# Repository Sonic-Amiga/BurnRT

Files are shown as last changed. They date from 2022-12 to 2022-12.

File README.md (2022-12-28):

# BurnRT fuse ROM programmer

 This is a programmer for old OTP fuse PROM chips. Developed and tested with russian
556РТ (556RT) series, however should also be able to work with Western analogs.

 The project has been restored from old P-CAD sources, shared on the original project
forum (https://zx-pk.ru/threads/15617-programmator-ppzu-155re3-556rt4-i-drugikh ;
russian language).

Current versions:

* Hardware v2.3
* Software v2.0
* Firmware v1.1
* Case v1.0

Unfortunately at the moment only a binary version of the software for Windows OS is available.

# Supported chips

155РЕ3 (155RE3), western analogs SN74188N, N8223N
556РТ4 (556RT4), western analog 82S126
556РТ11 (556RT11), western analog 82S129
556РТ5 (556RT5), western analog IP3604
556РТ17 (556RT17), western analog IP3624A
556РТ6 (556RT6)
556РТ7 (556RT7)
556РТ12, western analog N82S136
556РТ13, western analog N82S137
556РТ14 (556RT14)
556РТ15 (556RT15)

# Distribution

There was originally no clear license terms defined. I asked at least one of original authors
of the schematic; he was not against me opensourcing the design. I am not a fan of this legal
stuff; let's consider it public domain. Any improvements are welcome; i will gladly accept them
into the repository.

3D printed case design is licensed under Creative Commons license: https://www.thingiverse.com/thing:2911557

# Contacts

Please direct all questions to pavel_fedin@mail.ru or to the aforementioned forum.

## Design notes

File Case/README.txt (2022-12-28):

BurnRT programmer case by EvRU on Thingiverse: https://www.thingiverse.com/thing:2911557

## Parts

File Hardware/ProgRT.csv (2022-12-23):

Source: | D:\Projects\BurnRT\ProgRT_USB_KiCAD\ProgRT.kicad_sch
Date: | 11/21/2022 12:37:46 AM
Tool: | Eeschema (6.0.9)
Generator: | C:\Program Files\KiCad\6.0\bin\scripting\plugins/bom_csv_grouped_by_value.py
Component Count: | 68
Individual Components:
Item | Qty | Reference(s) | Value | LibPart | Footprint | Datasheet | Value
 |  | C1 | 22p | ProgRT-eagle-import:K10-17_1 | Capacitor_SMD:C_0805_2012Metric_Pad1.18x1.45mm_HandSolder |  | K10-17_1
 |  | C2 | 22p | ProgRT-eagle-import:K10-17_1 | Capacitor_SMD:C_0805_2012Metric_Pad1.18x1.45mm_HandSolder |  | K10-17_1
 |  | C3 | 220n | ProgRT-eagle-import:K10-17_1 | Capacitor_SMD:C_0805_2012Metric_Pad1.18x1.45mm_HandSolder |  | 220n
 |  | C4 | 100n | ProgRT-eagle-import:K10-17_1 | Capacitor_SMD:C_0805_2012Metric_Pad1.18x1.45mm_HandSolder |  | 100n
 |  | C5 | 100u 35V | ProgRT-eagle-import:K50-35_470UF__1 | Capacitor_THT:CP_Radial_D5.0mm_P2.50mm |  | 100u 35V
 |  | C6 | 100u 25V | ProgRT-eagle-import:K50-35_1 | Capacitor_THT:CP_Radial_D5.0mm_P2.50mm |  | 100u 25V
 |  | C7 | 100n | ProgRT-eagle-import:K10-17_1 | Capacitor_SMD:C_0805_2012Metric_Pad1.18x1.45mm_HandSolder |  | 100n
 |  | C8 | 100n | ProgRT-eagle-import:K10-17_1 | Capacitor_SMD:C_0805_2012Metric_Pad1.18x1.45mm_HandSolder |  | 100n
 |  | DA1 | DG408 | ProgRT-eagle-import:590KN6_1 | Package_SO:SOIC-16_3.9x9.9mm_P1.27mm |  | DG408
 |  | DA2 | 78M12 | ProgRT-eagle-import:7812_1 | Package_TO_SOT_SMD:TO-252-2 |  | 7812_1
 |  | DA3 | 78M05 | ProgRT-eagle-import:7805_1 | Package_TO_SOT_SMD:TO-252-2 |  | 7805_1
 |  | DD1 | PIC18F2550 | ProgRT-eagle-import:PIC18F2550_1 | Package_SO:SOIC-28W_7.5x18.7mm_P1.27mm |  | PIC18F2550
 |  | DD2 | 74HC574D | :1533IR37_1_2 | Package_SO:SOIC-20W_7.5x12.8mm_P1.27mm |  | 74HC574D
 |  | DD3 | 74HC574D | :1533IR37_1_2 | Package_SO:SOIC-20W_7.5x12.8mm_P1.27mm |  | 74HC574D
 |  | R1 | 4.7K | ProgRT-eagle-import:MLT_0125_B_1 | Resistor_SMD:R_0805_2012Metric_Pad1.20x1.40mm_HandSolder |  | MLT_0125_B_1
 |  | R2 | 5.1K | ProgRT-eagle-import:MLT_0125_B_1 | Resistor_SMD:R_0805_2012Metric_Pad1.20x1.40mm_HandSolder |  | 5.1K
 |  | R3 | 10K | ProgRT-eagle-import:MLT_0125_B_1 | Resistor_SMD:R_0805_2012Metric_Pad1.20x1.40mm_HandSolder |  | MLT_0125_B_1
 |  | R4 | 10K | ProgRT-eagle-import:MLT_0125_B_1 | Resistor_SMD:R_0805_2012Metric_Pad1.20x1.40mm_HandSolder |  | 10K
 |  | R5 | 10K | ProgRT-eagle-import:MLT_0125_B_1 | Resistor_SMD:R_0805_2012Metric_Pad1.20x1.40mm_HandSolder |  | 10K
 |  | R6 | 10K | ProgRT-eagle-import:MLT_0125_B_1 | Resistor_SMD:R_0805_2012Metric_Pad1.20x1.40mm_HandSolder |  | 10K
 |  | R7 | 47 | ProgRT-eagle-import:MLT_05_B_1 | Resistor_SMD:R_2512_6332Metric_Pad1.40x3.35mm_HandSolder |  | MLT_05_B_1
 |  | R8 | 5.1K | ProgRT-eagle-import:MLT_0125_B_1 | Resistor_SMD:R_0805_2012Metric_Pad1.20x1.40mm_HandSolder |  | MLT_0125_B_1
 |  | R9 | 430 | ProgRT-eagle-import:MLT_0125_B_1 | Resistor_SMD:R_0805_2012Metric_Pad1.20x1.40mm_HandSolder |  | 430
 |  | R10 | 10K | ProgRT-eagle-import:MLT_0125_B_1 | Resistor_SMD:R_0805_2012Metric_Pad1.20x1.40mm_HandSolder |  | MLT_0125_B_1
 |  | R11 | 5.1K | ProgRT-eagle-import:MLT_0125_B_1 | Resistor_SMD:R_0805_2012Metric_Pad1.20x1.40mm_HandSolder |  | MLT_0125_B_1
 |  | R12 | 430 | ProgRT-eagle-import:MLT_0125_B_1 | Resistor_SMD:R_0805_2012Metric_Pad1.20x1.40mm_HandSolder |  | MLT_0125_B_1
 |  | R13 | 5.1K | ProgRT-eagle-import:MLT_0125_B_1 | Resistor_SMD:R_0805_2012Metric_Pad1.20x1.40mm_HandSolder |  | MLT_0125_B_1
 |  | R14 | 10K | ProgRT-eagle-import:MLT_0125_B_1 | Resistor_SMD:R_0805_2012Metric_Pad1.20x1.40mm_HandSolder |  | MLT_0125_B_1
 |  | R15 | 10K | ProgRT-eagle-import:MLT_0125_B_1 | Resistor_SMD:R_0805_2012Metric_Pad1.20x1.40mm_HandSolder |  | MLT_0125_B_1
 |  | VD1 | BZV55-C5V1 | ProgRT-eagle-import:KS133A_B_1 | Diode_SMD:D_SOD-123 |  | KS133A_B_1
 |  | VD2 | BZV55-C5V1 | ProgRT-eagle-import:KS133A_B_1 | Diode_SMD:D_SOD-123 |  | KS133A_B_1
 |  | VD3 | BZV55-C5V1 | ProgRT-eagle-import:KS133A_B_1 | Diode_SMD:D_SOD-123 |  | KS133A_B_1
 |  | VD4 | BZV55-C5V1 | ProgRT-eagle-import:KS133A_B_1 | Diode_SMD:D_SOD-123 |  | KS133A_B_1
 |  | VD5 | BZV55-C5V1 | ProgRT-eagle-import:KS133A_B_1 | Diode_SMD:D_SOD-123 |  | KS133A_B_1
 |  | VD6 | BZV55-C5V1 | ProgRT-eagle-import:KS133A_B_1 | Diode_SMD:D_SOD-123 |  | KS133A_B_1
 |  | VD7 | BZV55-C5V1 | ProgRT-eagle-import:KS133A_B_1 | Diode_SMD:D_SOD-123 |  | KS133A_B_1
 |  | VD8 | BZV55-C5V1 | ProgRT-eagle-import:KS133A_B_1 | Diode_SMD:D_SOD-123 |  | KS133A_B_1
 |  | VD9 | BZV55-C5V1 | ProgRT-eagle-import:KS133A_B_1 | Diode_SMD:D_SOD-123 |  | KS133A_B_1
 |  | VD10 | BZV55-C5V1 | ProgRT-eagle-import:KS133A_B_1 | Diode_SMD:D_SOD-123 |  | KS133A_B_1
 |  | VD11 | BZV55-C5V1 | ProgRT-eagle-import:KS133A_B_1 | Diode_SMD:D_SOD-123 |  | KS133A_B_1
 |  | VD12 | BZV55-C5V1 | ProgRT-eagle-import:KS133A_B_1 | Diode_SMD:D_SOD-123 |  | KS133A_B_1
 |  | VD13 | BZV55-C5V1 | ProgRT-eagle-import:KS133A_B_1 | Diode_SMD:D_SOD-123 |  | KS133A_B_1
 |  | VD14 | BZV55-C5V1 | ProgRT-eagle-import:KS133A_B_1 | Diode_SMD:D_SOD-123 |  | KS133A_B_1
 |  | VD15 | BZV55-C5V1 | ProgRT-eagle-import:KS133A_B_1 | Diode_SMD:D_SOD-123 |  | KS133A_B_1
 |  | VD16 | BZV55-C5V1 | ProgRT-eagle-import:KS133A_B_1 | Diode_SMD:D_SOD-123 |  | KS133A_B_1
 |  | VD17 | M7 | ProgRT-eagle-import:1N400X_B_1 | Diode_SMD:D_SMA |  | 1N400X_B_1
 |  | VD18 | LL4148 | ProgRT-eagle-import:KD522_B_1 | Diode_SMD:D_SMA |  | КД522
 |  | VD19 | M7 | ProgRT-eagle-import:1N400X_B_1 | Diode_SMD:D_SMA |  | 1N400X_B_1
 |  | VD20 | M7 | ProgRT-eagle-import:1N400X_B_1 | Diode_SMD:D_SMA |  | 1N400X
 |  | VD21 | LL4148 | ProgRT-eagle-import:KD522_B_1 | Diode_SMD:D_SMA |  | КД522
 |  | VD22 | M7 | ProgRT-eagle-import:1N400X_B_1 | Diode_SMD:D_SMA |  | 1N400X_B_1
 |  | VD23 | M7 | ProgRT-eagle-import:1N400X_B_1 | Diode_SMD:D_SMA |  | 1N400X
 |  | VD24 | GREEN | Socet.SCH.eagle-eagle-import:AL307_1 | Diode_SMD:D_SOD-123F |  | AL307_1
 |  | VD25 | RED | Socet.SCH.eagle-eagle-import:AL307_1 | Diode_SMD:D_SOD-123F |  | AL307_1
 |  | VT1 | MJD127G | :KT973_1_1 | Package_TO_SOT_SMD:TO-252-2 |  | KT973_1_1
 |  | VT2 | BCX56 | ProgRT-eagle-import:KT503_1 | Package_TO_SOT_SMD:SOT-89-3 |  | KT503_1
 |  | VT3 | BCX56 | ProgRT-eagle-import:KT503_1 | Package_TO_SOT_SMD:SOT-89-3 |  | KT503_1
 |  | VT4 | BCX56 | ProgRT-eagle-import:KT503_1 | Package_TO_SOT_SMD:SOT-89-3 |  | KT503_1
 |  | VT5 | MJD127G | :KT973_1_1 | Package_TO_SOT_SMD:TO-252-2 |  | KT973_1_1
 |  | VT6 | BCX56 | ProgRT-eagle-import:KT503_1 | Package_TO_SOT_SMD:SOT-89-3 |  | KT503_1
 |  | XP1 | DC-005_1 | ProgRT-eagle-import:DC-005_1 | Connector_BarrelJack:BarrelJack_GCT_DCJ200-10-A_Horizontal |  | DC-005_1
 |  | XP2 | USB_TYPE_B_1 | ProgRT-eagle-import:USB_TYPE_B_1 | Connector_USB:USB_Mini-B_Lumberg_2486_01_Horizontal |  | USB_TYPE_B_1
 |  | XP3 | Conn_01x06 | Connector_Generic:Conn_01x06 | Connector_PinHeader_2.54mm:PinHeader_1x06_P2.54mm_Vertical | ~ | Conn_01x06
 |  | XS3 | 155РЕ3 | Socet.SCH.eagle-eagle-import:155RE3_ZIF_1 | Socket:DIP_Socket-16_W4.3_W5.08_W7.62_W10.16_W10.9_3M_216-3340-00-0602J |  | 155РЕ3
 |  | XS4 | 556РT4 | Socet.SCH.eagle-eagle-import:556RT4_ZIF_1 | Socket:DIP_Socket-16_W4.3_W5.08_W7.62_W10.16_W10.9_3M_216-3340-00-0602J |  | 556РT4
 |  | XS5 | 556РТ14 | Socet.SCH.eagle-eagle-import:556RT14_ZIF_1 | Socket:DIP_Socket-18_W4.3_W5.08_W7.62_W10.16_W10.9_3M_218-3341-00-0602J |  | 556РТ14
 |  | XS6 | 556РТ16 | Socet.SCH.eagle-eagle-import:556RT16_ZIF_1 | Socket:DIP_Socket-24_W11.9_W12.7_W15.24_W17.78_W18.5_3M_224-1275-00-0602J |  | 556РТ16
 |  | ZQ1 | 20 MHz | Device:Crystal | Crystal:Crystal_HC49-U_Vertical | ~ | Crystal
Collated Components:
Item | Qty | Reference(s) | Value | LibPart | Footprint | Datasheet | Value
1 | 2 | C1, C2 | 22p | ProgRT-eagle-import:K10-17_1 | Capacitor_SMD:C_0805_2012Metric_Pad1.18x1.45mm_HandSolder |  | K10-17_1
2 | 1 | C3 | 220n | ProgRT-eagle-import:K10-17_1 | Capacitor_SMD:C_0805_2012Metric_Pad1.18x1.45mm_HandSolder |  | 220n
3 | 3 | C4, C7, C8 | 100n | ProgRT-eagle-import:K10-17_1 | Capacitor_SMD:C_0805_2012Metric_Pad1.18x1.45mm_HandSolder |  | 100n
4 | 1 | C5 | 100u 35V | ProgRT-eagle-import:K50-35_470UF__1 | Capacitor_THT:CP_Radial_D5.0mm_P2.50mm |  | 100u 35V
5 | 1 | C6 | 100u 25V | ProgRT-eagle-import:K50-35_1 | Capacitor_THT:CP_Radial_D5.0mm_P2.50mm |  | 100u 25V
6 | 1 | DA1 | DG408 | ProgRT-eagle-import:590KN6_1 | Package_SO:SOIC-16_3.9x9.9mm_P1.27mm |  | DG408
7 | 1 | DA2 | 78M12 | ProgRT-eagle-import:7812_1 | Package_TO_SOT_SMD:TO-252-2 |  | 7812_1
8 | 1 | DA3 | 78M05 | ProgRT-eagle-import:7805_1 | Package_TO_SOT_SMD:TO-252-2 |  | 7805_1
9 | 1 | DD1 | PIC18F2550 | ProgRT-eagle-import:PIC18F2550_1 | Package_SO:SOIC-28W_7.5x18.7mm_P1.27mm |  | PIC18F2550
10 | 2 | DD2, DD3 | 74HC574D | :1533IR37_1_2 | Package_SO:SOIC-20W_7.5x12.8mm_P1.27mm |  | 74HC574D
11 | 1 | R1 | 4.7K | ProgRT-eagle-import:MLT_0125_B_1 | Resistor_SMD:R_0805_2012Metric_Pad1.20x1.40mm_HandSolder |  | MLT_0125_B_1
12 | 4 | R2, R8, R11, R13 | 5.1K | ProgRT-eagle-import:MLT_0125_B_1 | Resistor_SMD:R_0805_2012Metric_Pad1.20x1.40mm_HandSolder |  | 5.1K
13 | 7 | R3, R4, R5, R6, R10, R14, R15 | 10K | ProgRT-eagle-import:MLT_0125_B_1 | Resistor_SMD:R_0805_2012Metric_Pad1.20x1.40mm_HandSolder |  | 10K
14 | 1 | R7 | 47 | ProgRT-eagle-import:MLT_05_B_1 | Resistor_SMD:R_2512_6332Metric_Pad1.40x3.35mm_HandSolder |  | MLT_05_B_1
15 | 2 | R9, R12 | 430 | ProgRT-eagle-import:MLT_0125_B_1 | Resistor_SMD:R_0805_2012Metric_Pad1.20x1.40mm_HandSolder |  | 430
16 | 16 | VD1, VD2, VD3, VD4, VD5, VD6, VD7, VD8, VD9, VD10, VD11, VD12, VD13, VD14, VD15, VD16 | BZV55-C5V1 | ProgRT-eagle-import:KS133A_B_1 | Diode_SMD:D_SOD-123 |  | KS133A_B_1
17 | 5 | VD17, VD19, VD20, VD22, VD23 | M7 | ProgRT-eagle-import:1N400X_B_1 | Diode_SMD:D_SMA |  | 1N400X
18 | 2 | VD18, VD21 | LL4148 | ProgRT-eagle-import:KD522_B_1 | Diode_SMD:D_SMA |  | КД522
19 | 1 | VD24 | GREEN | Socet.SCH.eagle-eagle-import:AL307_1 | Diode_SMD:D_SOD-123F |  | AL307_1
20 | 1 | VD25 | RED | Socet.SCH.eagle-eagle-import:AL307_1 | Diode_SMD:D_SOD-123F |  | AL307_1
21 | 2 | VT1, VT5 | MJD127G | :KT973_1_1 | Package_TO_SOT_SMD:TO-252-2 |  | KT973_1_1
22 | 4 | VT2, VT3, VT4, VT6 | BCX56 | ProgRT-eagle-import:KT503_1 | Package_TO_SOT_SMD:SOT-89-3 |  | KT503_1
23 | 1 | XP1 | DC-005_1 | ProgRT-eagle-import:DC-005_1 | Connector_BarrelJack:BarrelJack_GCT_DCJ200-10-A_Horizontal |  | DC-005_1
24 | 1 | XP2 | USB_TYPE_B_1 | ProgRT-eagle-import:USB_TYPE_B_1 | Connector_USB:USB_Mini-B_Lumberg_2486_01_Horizontal |  | USB_TYPE_B_1
25 | 1 | XP3 | Conn_01x06 | Connector_Generic:Conn_01x06 | Connector_PinHeader_2.54mm:PinHeader_1x06_P2.54mm_Vertical | ~ | Conn_01x06
26 | 1 | XS3 | 155РЕ3 | Socet.SCH.eagle-eagle-import:155RE3_ZIF_1 | Socket:DIP_Socket-16_W4.3_W5.08_W7.62_W10.16_W10.9_3M_216-3340-00-0602J |  | 155РЕ3
27 | 1 | XS4 | 556РT4 | Socet.SCH.eagle-eagle-import:556RT4_ZIF_1 | Socket:DIP_Socket-16_W4.3_W5.08_W7.62_W10.16_W10.9_3M_216-3340-00-0602J |  | 556РT4
28 | 1 | XS5 | 556РТ14 | Socet.SCH.eagle-eagle-import:556RT14_ZIF_1 | Socket:DIP_Socket-18_W4.3_W5.08_W7.62_W10.16_W10.9_3M_218-3341-00-0602J |  | 556РТ14
29 | 1 | XS6 | 556РТ16 | Socet.SCH.eagle-eagle-import:556RT16_ZIF_1 | Socket:DIP_Socket-24_W11.9_W12.7_W15.24_W17.78_W18.5_3M_224-1275-00-0602J |  | 556РТ16
30 | 1 | ZQ1 | 20 MHz | Device:Crystal | Crystal:Crystal_HC49-U_Vertical | ~ | Crystal

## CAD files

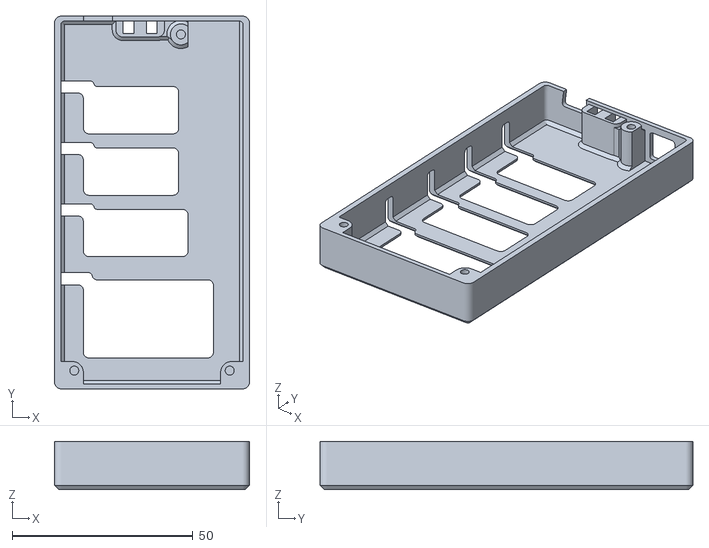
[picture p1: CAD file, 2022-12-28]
Case/burnrt_case_top.stl
54.0 x 103.2 x 13.4

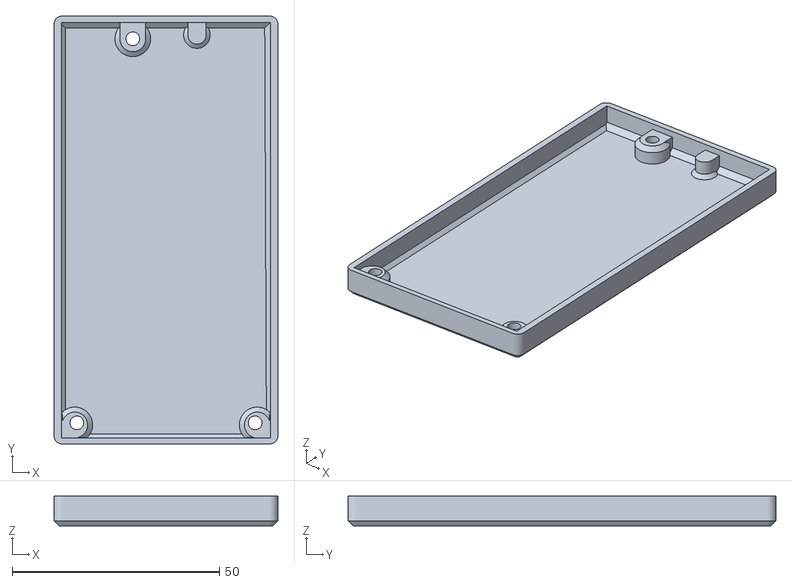
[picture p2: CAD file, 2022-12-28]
Case/burnrt_case_bottom.stl
54.0 x 103.2 x 7.20

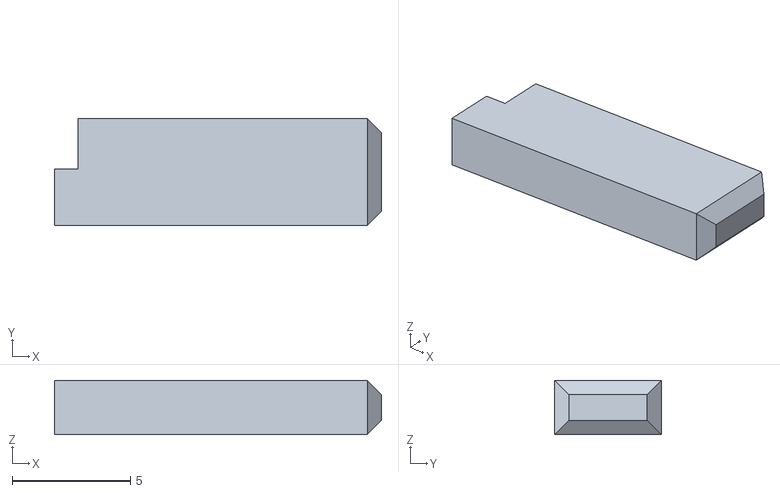
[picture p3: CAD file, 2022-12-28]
Case/burnrt_case_light.stl
13.8 x 4.51 x 2.28

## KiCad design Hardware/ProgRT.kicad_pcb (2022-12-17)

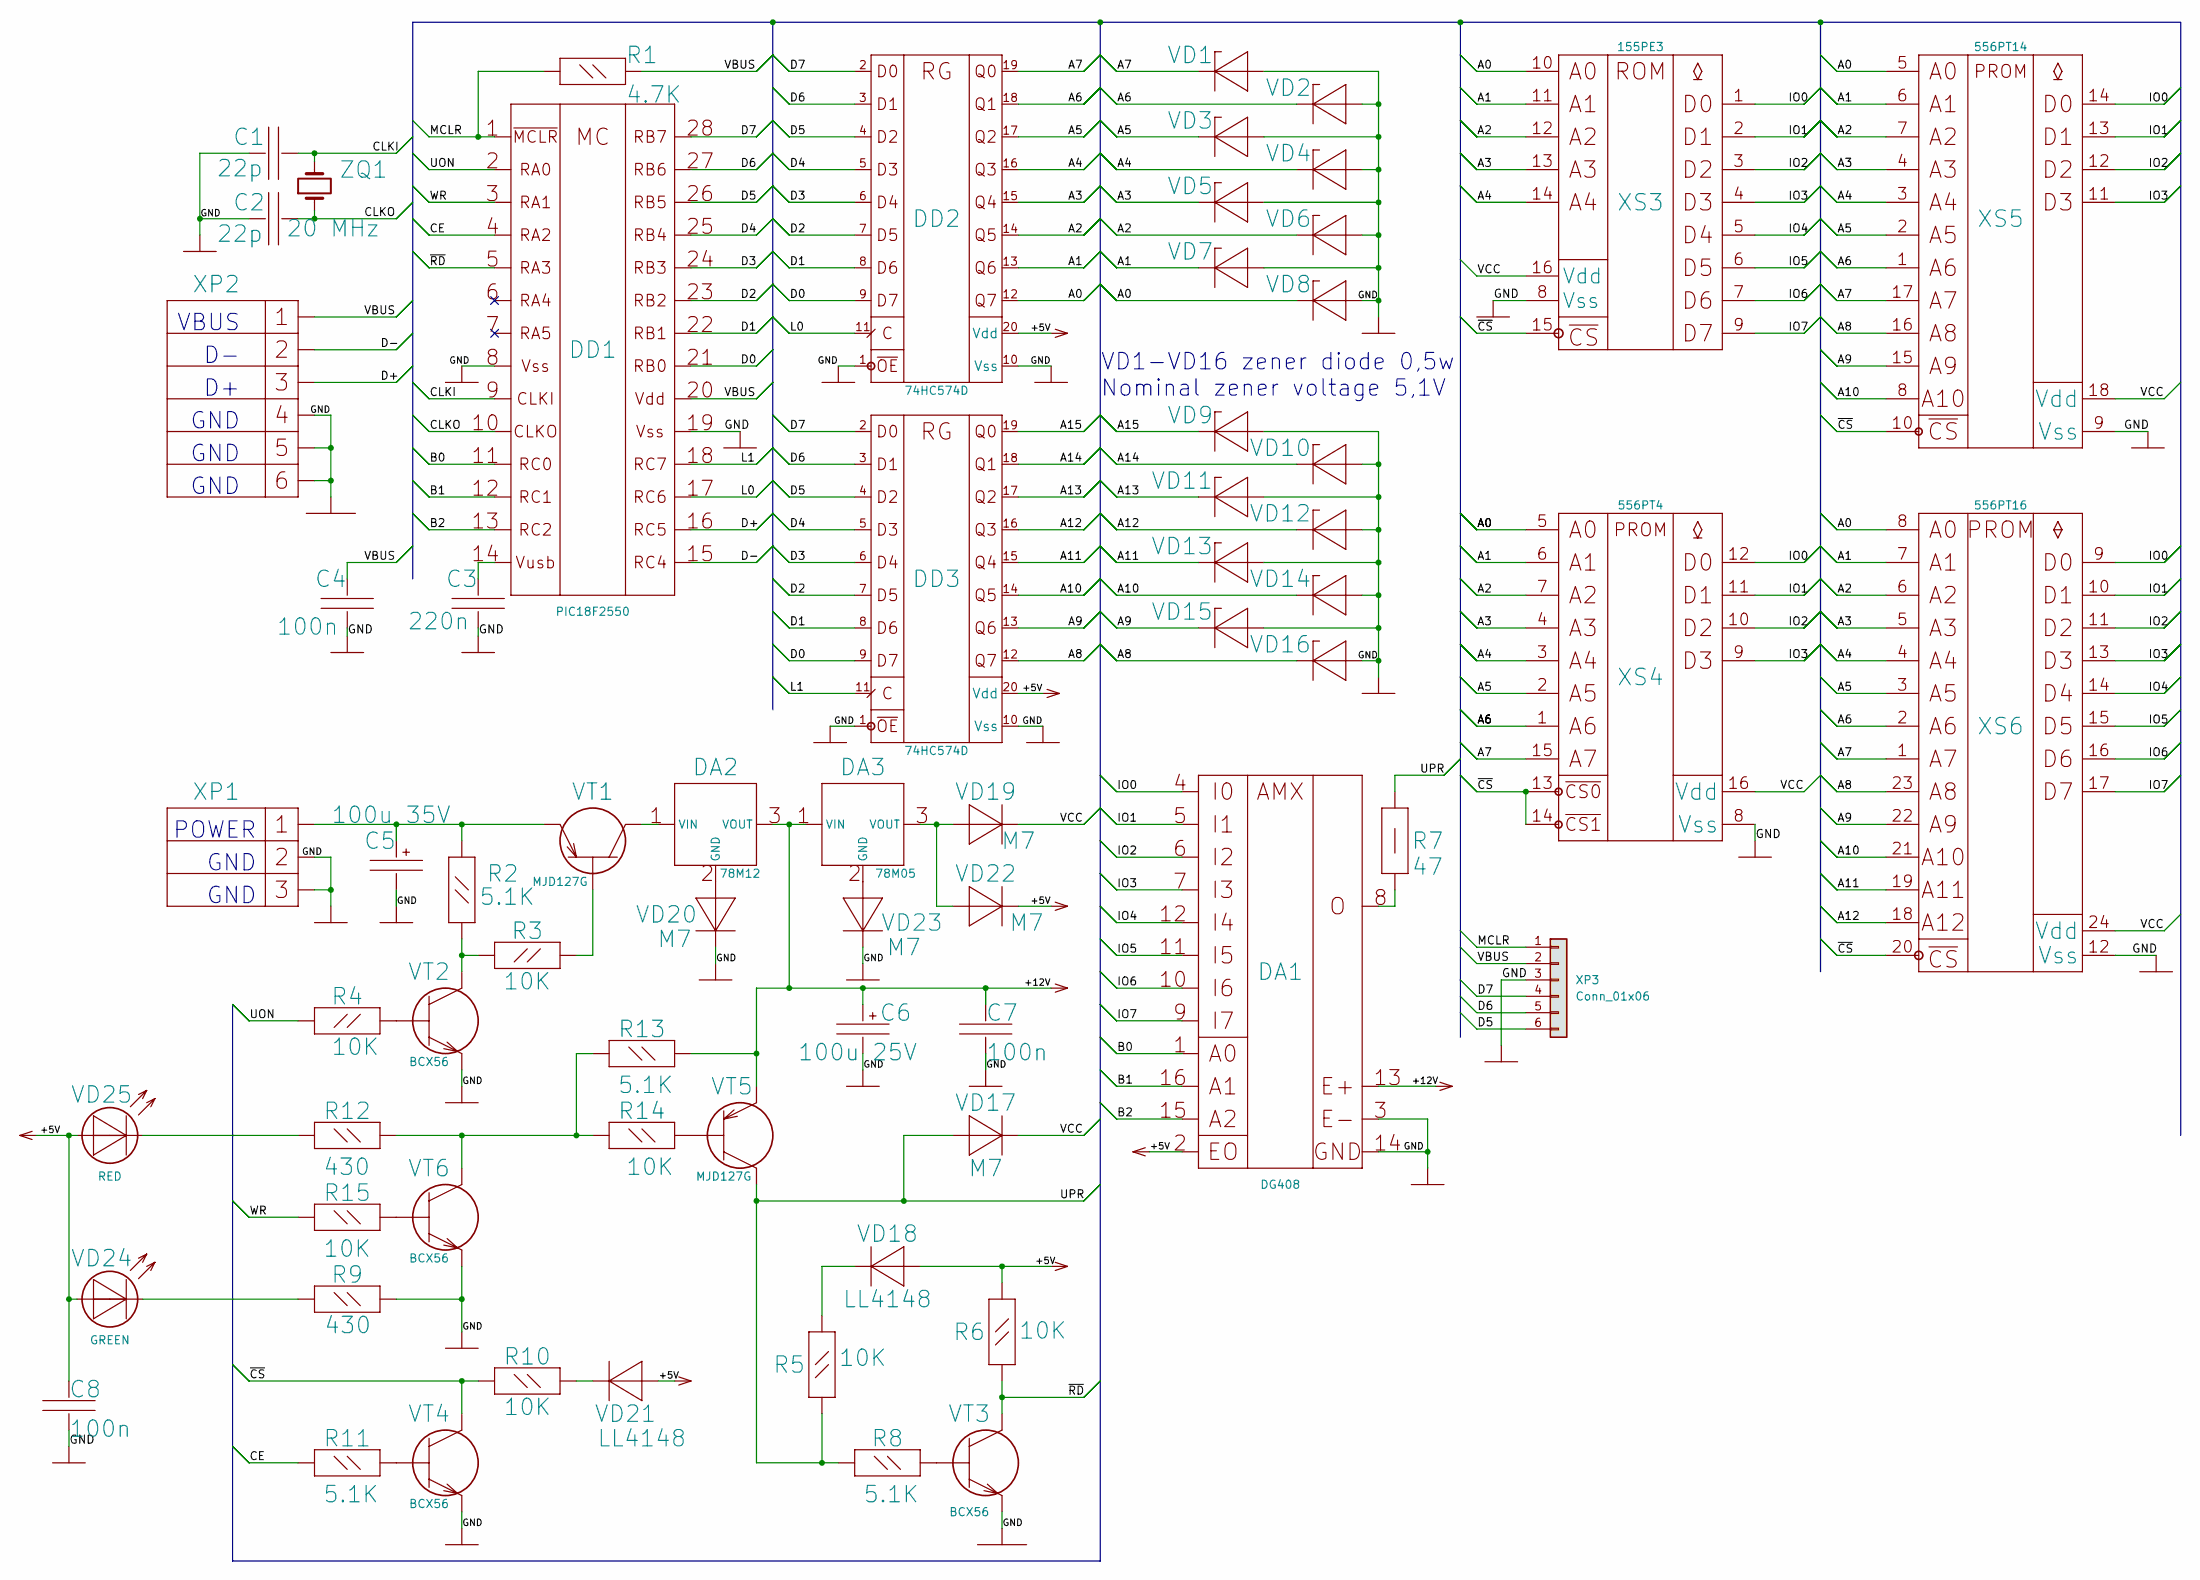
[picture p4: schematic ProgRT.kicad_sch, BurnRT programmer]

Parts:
C1, C2: 22p; C_0805_2012Metric_Pad1.18x1.45mm_HandSolder
C3: 220n; C_0805_2012Metric_Pad1.18x1.45mm_HandSolder
C4, C7: 100n; C_0805_2012Metric_Pad1.18x1.45mm_HandSolder
C5: 100u 35V; CP_Radial_D8.0mm_P3.80mm
C6: 100u 25V; CP_Radial_D8.0mm_P3.80mm
C8: 100n; C_1206_3216Metric_Pad1.33x1.80mm_HandSolder
DA1: DG408; SOIC-16_3.9x9.9mm_P1.27mm
DA2: 78M12; TO-252-2
DA3: 78M05; TO-252-2
DD1: PIC18F2550; SOIC-28W_7.5x18.7mm_P1.27mm
DD2, DD3: 74HC574D; SOIC-20W_7.5x12.8mm_P1.27mm
R1: 4.7K; R_0805_2012Metric_Pad1.20x1.40mm_HandSolder
R2, R8, R11, R13: 5.1K; R_0805_2012Metric_Pad1.20x1.40mm_HandSolder
R3: R_0805_2012Metric_Pad1.20x1.40mm_HandSolder
R4, R5, R6, R10, R14, R15: 10K; R_0805_2012Metric_Pad1.20x1.40mm_HandSolder
R7: 47; R_2512_6332Metric_Pad1.40x3.35mm_HandSolder
R9, R12: 430; R_0805_2012Metric_Pad1.20x1.40mm_HandSolder
VD1, VD2, VD3, VD4, VD5, VD6, VD7, VD8, VD9, VD10, VD11, VD12, VD13, VD14, VD15, VD16: BZV55-C5V1; D_MiniMELF
VD17, VD19, VD20, VD22: M7; D_SMA
VD18, VD21: LL4148; D_SMA
VD23: D_SMA
VD24: GREEN; LED_1206_3216Metric_Pad1.42x1.75mm_HandSolder
VD25: RED; LED_1206_3216Metric_Pad1.42x1.75mm_HandSolder
VT1, VT5: MJD127G; TO-252-2
VT2, VT3, VT4, VT6: BCX56; SOT-89-3
XP1: DC-005_1; BarrelJack_GCT_DCJ200-10-A_Horizontal
XP2: USB_TYPE_B_1; USB_Mini-B_Lumberg_2486_01_Horizontal
XP3: Conn_01x06; PinHeader_1x06_P2.54mm_Vertical
XS3: 155РЕ3; DIP_Socket-16_W4.3_W5.08_W7.62_W10.16_W10.9_3M_216-3340-00-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
XS4: 556РT4; DIP_Socket-16_W4.3_W5.08_W7.62_W10.16_W10.9_3M_216-3340-00-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
XS5: 556РТ14; DIP_Socket-18_W4.3_W5.08_W7.62_W10.16_W10.9_3M_218-3341-00-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
XS6: 556РТ16; DIP_Socket-24_W11.9_W12.7_W15.24_W17.78_W18.5_3M_224-1275-0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
ZQ1: 20 MHz; Crystal_HC49-U_Vertical

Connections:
/A0: DD2.12 (Q7), VD8.1 (C), XS3.10 (A0), XS4.5 (A0), XS5.5 (A0), XS6.8 (A0)
/A1: DD2.13 (Q6), VD7.1 (C), XS3.11 (A1), XS4.6 (A1), XS5.6 (A1), XS6.7 (A1)
/A2: DD2.14 (Q5), VD6.1 (C), XS3.12 (A2), XS4.7 (A2), XS5.7 (A2), XS6.6 (A2)
/A3: DD2.15 (Q4), VD5.1 (C), XS3.13 (A3), XS4.4 (A3), XS5.4 (A3), XS6.5 (A3)
/A4: DD2.16 (Q3), VD4.1 (C), XS3.14 (A4), XS4.3 (A4), XS5.3 (A4), XS6.4 (A4)
/A5: DD2.17 (Q2), VD3.1 (C), XS4.2 (A5), XS5.2 (A5), XS6.3 (A5)
/A6: DD2.18 (Q1), VD2.1 (C), XS4.1 (A6), XS5.1 (A6), XS6.2 (A6)
/A7: DD2.19 (Q0), VD1.1 (C), XS4.15 (A7), XS5.17 (A7), XS6.1 (A7)
/A8: DD3.12 (Q7), VD16.1 (C), XS5.16 (A8), XS6.23 (A8)
/A9: DD3.13 (Q6), VD15.1 (C), XS5.15 (A9), XS6.22 (A9)
/A10: DD3.14 (Q5), VD14.1 (C), XS5.8 (A10), XS6.21 (A10)
/A11: DD3.15 (Q4), VD13.1 (C), XS6.19 (A11)
/A12: DD3.16 (Q3), VD12.1 (C), XS6.18 (A12)
/A13: DD3.17 (Q2), VD11.1 (C)
/A14: DD3.18 (Q1), VD10.1 (C)
/A15: DD3.19 (Q0), VD9.1 (C)
/B0: DA1.1 (A0), DD1.11 (RC0)
/B1: DA1.16 (A1), DD1.12 (RC1)
/B2: DA1.15 (A2), DD1.13 (RC2)
/CE: DD1.4 (RA2), R11.1
/CLKI: C1.1 (2), DD1.9 (CLKI), ZQ1.2
/CLKO: C2.1 (2), DD1.10 (CLKO), ZQ1.1
/D0: DD1.21 (RB0), DD2.9 (D7), DD3.9 (D7)
/D1: DD1.22 (RB1), DD2.8 (D6), DD3.8 (D6)
/D2: DD1.23 (RB2), DD2.7 (D5), DD3.7 (D5)
/D3: DD1.24 (RB3), DD2.6 (D4), DD3.6 (D4)
/D4: DD1.25 (RB4), DD2.5 (D3), DD3.5 (D3)
/D5: DD1.26 (RB5), DD2.4 (D2), DD3.4 (D2), XP3.6
/D6: DD1.27 (RB6), DD2.3 (D1), DD3.3 (D1), XP3.5
/D7: DD1.28 (RB7), DD2.2 (D0), DD3.2 (D0), XP3.4
/D+: DD1.16 (RC5), XP2.3 (D+)
/D-: DD1.15 (RC4), XP2.2 (D-)
/GND: C1.2 (1), C2.2 (1), C3.2 (1), C4.2 (1), C5.2, C6.2, C7.1 (2), C8.1 (2), DA1.3 (E-), DA1.14 (GND), DD1.8 (VSS@1), DD1.19 (VSS@2), DD2.1 (!OE), DD2.10 (Vss), DD3.1 (!OE), DD3.10 (Vss), R9.1, VD1.2 (A), VD2.2 (A), VD3.2 (A), VD4.2 (A), VD5.2 (A), VD6.2 (A), VD7.2 (A), VD8.2 (A), VD9.2 (A), VD10.2 (A), VD11.2 (A), VD12.2 (A), VD13.2 (A), VD14.2 (A), VD15.2 (A), VD16.2 (A), VD20.1 (C), VD23.1 (C), VT2.3 (E), VT3.3 (E), VT4.3 (E), VT6.3 (E), XP1.2, XP1.3, XP2.4 (GND@2), XP2.5 (GND@1), XP2.6 (GND@3), XP3.3, XS3.8 (Vss), XS4.8 (Vss), XS5.9 (Vss), XS6.12 (Vss)
/IO0: DA1.4 (I0), XS3.1 (D0), XS4.12 (D0), XS5.14 (D0), XS6.9 (D0)
/IO1: DA1.5 (I1), XS3.2 (D1), XS4.11 (D1), XS5.13 (D1), XS6.10 (D1)
/IO2: DA1.6 (I2), XS3.3 (D2), XS4.10 (D2), XS5.12 (D2), XS6.11 (D2)
/IO3: DA1.7 (I3), XS3.4 (D3), XS4.9 (D3), XS5.11 (D3), XS6.13 (D3)
/IO4: DA1.12 (I4), XS3.5 (D4), XS6.14 (D4)
/IO5: DA1.11 (I5), XS3.6 (D5), XS6.15 (D5)
/IO6: DA1.10 (I6), XS3.7 (D6), XS6.16 (D6)
/IO7: DA1.9 (I7), XS3.9 (D7), XS6.17 (D7)
/L0: DD1.17 (RC6), DD2.11 (C)
/L1: DD1.18 (RC7), DD3.11 (C)
/MCLR: DD1.1 (!MCLR), R1.1, XP3.1
/UON: DD1.2 (RA0), R4.1
/UPR: R5.1, R7.1, R8.1, VD17.2 (A), VT5.2 (C)
/VBUS: C4.1 (2), DD1.20 (VDD), R1.2, XP2.1 (VBUS), XP3.2
/VCC: VD17.1 (C), VD19.1 (C), XS3.16 (Vdd), XS4.16 (Vdd), XS5.18 (Vdd), XS6.24 (Vdd)
/WR: DD1.3 (RA1), R15.1
/~CS: R10.1, VT4.2 (C), XS3.15 (!CS), XS4.13 (~CS0), XS4.14 (~CS1), XS5.10 (!CS), XS6.20 (~CS)
/~RD: DD1.5 (RA3), R6.1, VT3.2 (C)
unnamed: C3.1 (2), DD1.14 (VUSB)
unnamed: C5.1, R2.2, VT1.3 (E), XP1.1
unnamed: DA1.8 (O), R7.2
unnamed: DA2.1 (VIN), VT1.2 (C)
unnamed: DA2.2 (GND), VD20.2 (A)
unnamed: DA3.2 (GND), VD23.2 (A)
unnamed: DA3.3 (VOUT), VD19.2 (A), VD22.2 (A)
unnamed: R2.1, R3.1, VT2.2 (C)
unnamed: R3.2, VT1.1 (B)
unnamed: R4.2, VT2.1 (B)
unnamed: R5.2, VD18.1 (C)
unnamed: R8.2, VT3.1 (B)
unnamed: R9.2, VD24.1 (C)
unnamed: R10.2, VD21.1 (C)
unnamed: R11.2, VT4.1 (B)
unnamed: R12.1, VD25.1 (C)
unnamed: R12.2, R13.1, R14.1, VT6.2 (C)
unnamed: R14.2, VT5.1 (B)
unnamed: R15.2, VT6.1 (B)

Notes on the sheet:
GND
VBUS
POWER
VD1-VD16 zener diode 0,5w Nominal zener voltage 5,1V

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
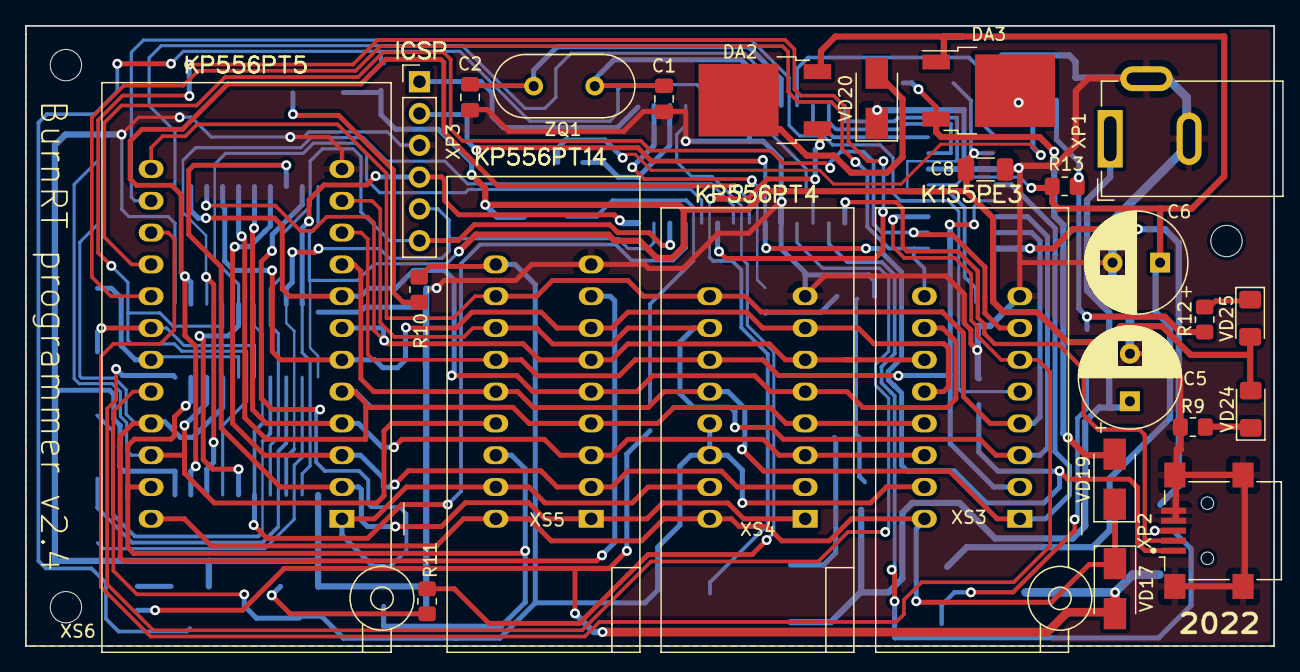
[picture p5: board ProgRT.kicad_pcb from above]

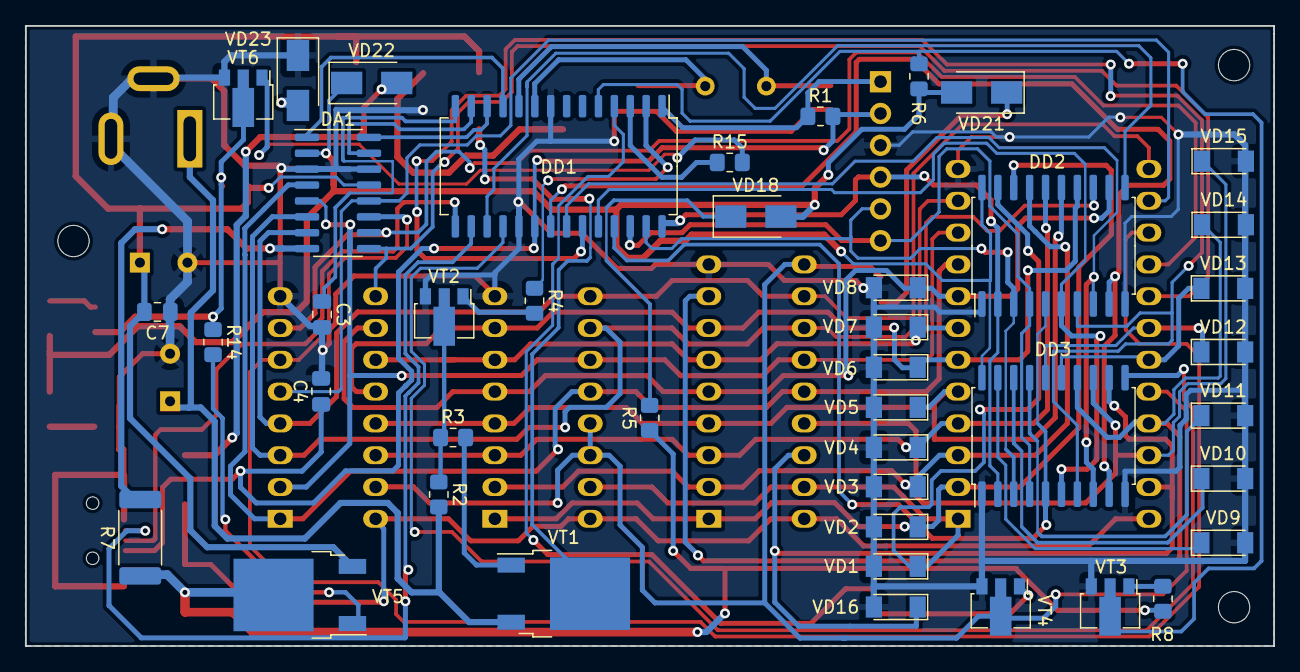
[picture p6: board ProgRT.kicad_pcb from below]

Board: 2 copper layers, 99.7 x 49.5 mm, 68 parts (43 on the bottom side), 72 nets.

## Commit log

2022-11-18 Initial import
    The latest schematic, imported from ancient P-CAD format and meticulously
    restored by hands
    [ProgRT.kicad_sch]
2022-11-18 PCB from the original single-board layout
    Recovered the PCB from schematic and old gerbers. The gerbers didn't contain
    recent fixups, these parts need to be placed
    [ProgRT.kicad_pcb, ProgRT.kicad_sch]
2022-11-20 Add missing parts
    ICSP connector and C8 capacitor
    [ProgRT.kicad_sch]
2022-11-20 Routing complete
    All the parts placed and connected
    [ProgRT.kicad_pcb]
2022-11-20 Fix DRC errors
    DRC now (almost) passes. Only ZIF socket courtyard overlaps remain, i can't do
    anything about them, at least for now
    [ProgRT.kicad_pcb]
2022-11-20 Add mounting holes
    Replace drawing with proper mounting hole definitions
    [ProgRT.kicad_pcb]
2022-11-29 Some PCB optimizations
    Removed some vias, rerouted some tracks, added ground plane
    [ProgRT.kicad_pcb]
2022-11-29 Small footprint corrections
    - use SMF footprint for Zener diodes, easier to hand-solder
    - use larger footprint for polar caps, extends availability
    - use 3216 LEDs, easier available and easier to hand-solder
    [ProgRT.kicad_pcb, ProgRT.kicad_sch]
2022-11-30 Use MiniMELF Zeners
    Change Zener diodes package again to MiniMELF. Should be easier to hand-solder.
    [ProgRT.kicad_pcb, ProgRT.kicad_sch]
2022-12-17 Fix diodes on silk screen
    Diodes were reversed because pin numbers got corrupted during import. Fix them,
    so that silk screen and fab layer is displayed correctly
    [ProgRT.kicad_pcb, ProgRT.kicad_sch]
2022-12-23 Some fixups
    - Finally remove the missing "empty" frame file
    - Bring back diode types after pins fixup
    [ProgRT.kicad_sch]
2022-12-23 Reorganize project
    Move hardware design to a subfolder and provide the current software.
    Unfortunately only binaries are available at the moment
    [155RE3.CFG, 556RT12.CFG, 556RT14.CFG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]
2022-12-28 Add 3D printed case design
    Case design by EvRU from ThingVerse. Let's have all the parts together
    [burnrt_case_bottom.stl, burnrt_case_light.stl, burnrt_case_top.stl]
